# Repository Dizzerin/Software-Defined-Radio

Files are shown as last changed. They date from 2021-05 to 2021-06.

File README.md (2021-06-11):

# Software-Defined-Radio
This project is a quadrature sampling down converter software defined radio reciver for Engineering Electronics II at Walla Walla University.
My partners for this project were [Darius Felder](https://github.com/darius3241) and [Eric Walsh](https://github.com/Eric-Walsh).
For a quick look at the final results of our project jump to [results](#results).
For a quick setup guide jump to [Quisk setup](#quisk-setup).

## Design Objectives
Our professor, [Dr. Rob Frohne](https://github.com/frohro), gave us the following design objectives:
  1. Minimum discernible signal less than 1μV
  2. Good image rejection
  3. Low noise figure
  4. Inexpensive to build

  1. **Simple Design**: We wanted our design to be easy to understand and construct
  2. **Ease of Construction**: We wanted to build a simple radio that works
  3. **Low Cost**: Our budget for this project was $30
  
## Overview
The Software Defined Radio (SDR) receiver connects to an antenna and covers the filtering, mixing, and amplification of the desired signal. It then connects a sound card within a computer and software handles the demodulation of the signal into playable audio. The mixing is handled using an Arduino Nano running code provided to us by our Professor, [Dr. Rob Frohne](https://github.com/frohro), which interfaces with [Quisk](https://james.ahlstrom.name/quisk/), an SDR that controls the receiver through the Arduino. Using Quisk, the radio can be tuned to a certain frequency by adjusting the speed of the local oscillator used in the mixing process. Our budget on this project to keep with the low-cost aspect was about $30 including fabrication of the PCB and the required components. 

Note: Overview section by [Konrad McClure](https://github.com/KonradMcClure)

## Theory
The basics of the SDR Receiver are shown below in the block diagram, with the blue components being defined by software. An antenna picks up the radio signal and passes it through a bandpass filter. This filter will attenuate any signals outside our desired range of 6–16 MHz. This is then passed through a Tayloe Mixer, also known as the Tayloe Quadrature Product Detector. The Tayloe Mixer is a simple and efficient mixer that uses a 1:4 demultiplexer and operational amplifiers to generate the I and Q quadrature signals for demodulation. After the signal has been split into four bandbase signals, they are amplified and combined into the I and Q quadrature signals. Those signals go through a final Low-Pass filter that will attenuate signals above 100KHz in frequency, effectively smoothing the output signal. This signal is then sent via 3.5mm audio cable to the soundcard which demodulates the signal. Quisk can then read the input from the sound card and play it. Quisk also interfaces to the Arduino Nano to set the speed of the local oscillator for tuning into the desired frequency.

Note: This Theory Section is a slightly modified version of work originally written by [Konrad McClure](https://github.com/KonradMcClure)

## Design 
Here is a basic block diagram of our design:



## Schematic 


### List of components


### Voltage smoother 
This was added to smooth out 5V power supply from USB. This will help elimate supply noise.



### Voltage converter
This device converts the 5V logic of the arduino nano to the 3.3V logic of the Si5351a for both directions.



### Local Oscillator (Si5351a)
The local oscillator we used, SI5351-AB-GT clock generator was selected largely due to the fact that Dr. Frohne has used this chip with success.



### Mixer (tayloe)
The Tayloe Mixer is a mixer design as seen in [this paper](http://www.norcalqrp.org/files/Tayloe_mixer_x3a.pdf) by Dan Tayloe. We chose it due to its relatively simple and elegant design. It utilizes a [two-channel SN74CBT multiplexer](http://www.ti.com/lit/ds/symlink/sn74cbt3253.pdf?ts=1591655665924) and a pair of [INA821ID single gain resistor instrumentation amplifiers](http://www.ti.com/lit/ds/symlink/ina821.pdf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). To be more specific, Tayloe describes this as a "switching integrator," rather than a mixer, since a mixer normally produces both a sum and difference frequency of the RF and LO signals.



### Amplifiers
A Multiple feedback low pass filter and amplifier was used.



### Arduino Nano


## Simulation
Complete LTSpice model:



### Results of simulation


## Quisk setup
According to the [Quisk pip project description](https://pypi.org/project/quisk/), the [Quisk software](https://james.ahlstrom.name/quisk/) is "Software Defined Radio (SDR) transceiver software. You supply radio hardware that converts signals at the antenna to complex (I/Q) data at an intermediate frequency (IF). Data can come from a sound card, Ethernet or USB. Quisk then filters and demodulates the data and sends the audio to your speakers or headphones."  We used Quisk in our project for just this purpose.

To get Quisk up and running with our radio, simply:
1. Flash the [openradio_quisk.ino](openradio_quisk.ino) file to the arduino nano microcontroller.
2. Start Quisk and configure a new radio.  Point Quisk to the [quisk_conf_openradio.py](quisk_conf_openradio.py) file.  Alternatively you can simply copy the file to your home directory (~/.quisk_conf.py).

	Note: You may need to configure the following settings in this python file:
	* Sound card settings
	* Serial port settings
	
3. Restart Quisk tune to your desired frequency and listen away!

## Board build up plan 
See [board build up plan](https://github.com/darius3241/Software-Defined-Radio/wiki/Board-build-up-plan).

## Revisions and debugging 
See [revisions and debugging](https://github.com/darius3241/Software-Defined-Radio/wiki/Debugging-and-Revisions).

## Complete Design 
Photo of our complete board:



## Results
In the end, we had about 1μV of sensitivity and between 10 and 30 dB of image rejection. (Darius’
radio had about 10dB of rejection while mine had about 30dB of image rejection). Though our radios
are working, they have less sensitivity than desired and when we examine the waterfall spectral display
on Quisk there are some distinct lines. We believe these are from signals on the USB input, so it may be
worthwhile to investigate isolating this further in future revisions.

Credit to: Dr. Frohne for his extensive help with the debugging process.

## Future Revision Recomendations
Other recommendations for future revisions include using continuous rows of pin headers for test
points instead of single pin headers to ease soldering, include better ground test points (perhaps two
pads to solder a wire between which ground clips can be clipped onto), moving plastic components
further from surface mount chips which may need to be de-soldered, and including jumpers to allow the
op amps to be powered from an alternate power source separate from the 5V circuit so additional
power can be provided if desired without damaging other components.

## External tools used:
[Multiple Feedback Low-Pass Filter Design Tool](http://sim.okawa-denshi.jp/en/OPtazyuLowkeisan.htm)

[Third Order Butterworth Bandpass Filter Design Tool](https://rf-tools.com/lc-filter/)

## Credits
[Darius Felder](https://github.com/darius3241) - project partner primarily responsible for testing, simulations, and documentation

[Eric Walsh](https://github.com/Eric-Walsh) - project partner primarily responsible for testing and LTSpice simulations

[Dr. Frohne](https://github.com/frohro) - class professor

[Konrad McClure](https://github.com/KonradMcClure) - previous project pioneer

[Caleb Froelich](https://github.com/froeca) - previous project pioneer

[Jordyn Watkins](https://github.com/greenjacketgirl) - previous project pioneer

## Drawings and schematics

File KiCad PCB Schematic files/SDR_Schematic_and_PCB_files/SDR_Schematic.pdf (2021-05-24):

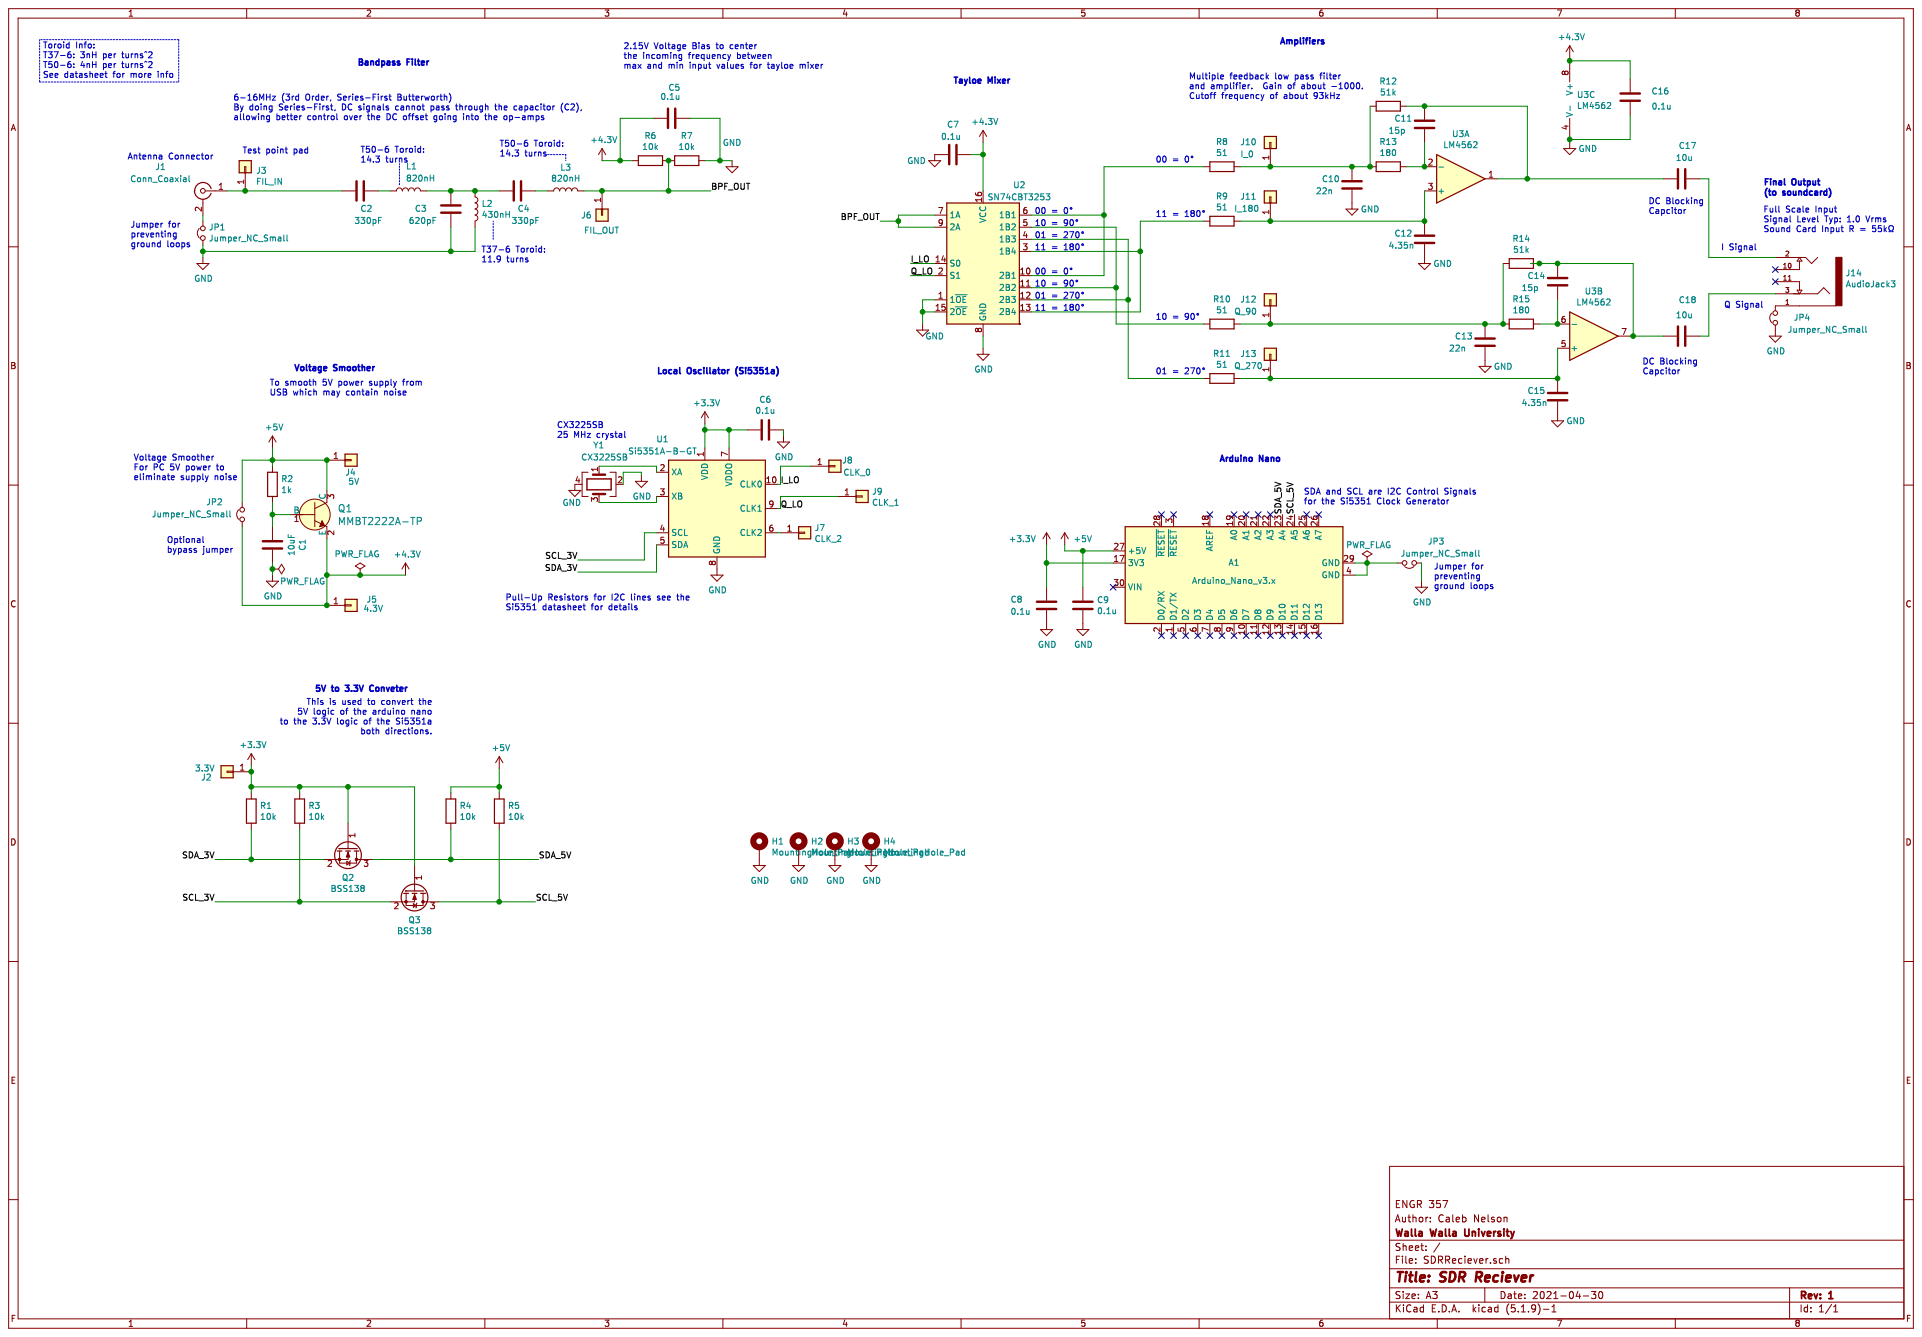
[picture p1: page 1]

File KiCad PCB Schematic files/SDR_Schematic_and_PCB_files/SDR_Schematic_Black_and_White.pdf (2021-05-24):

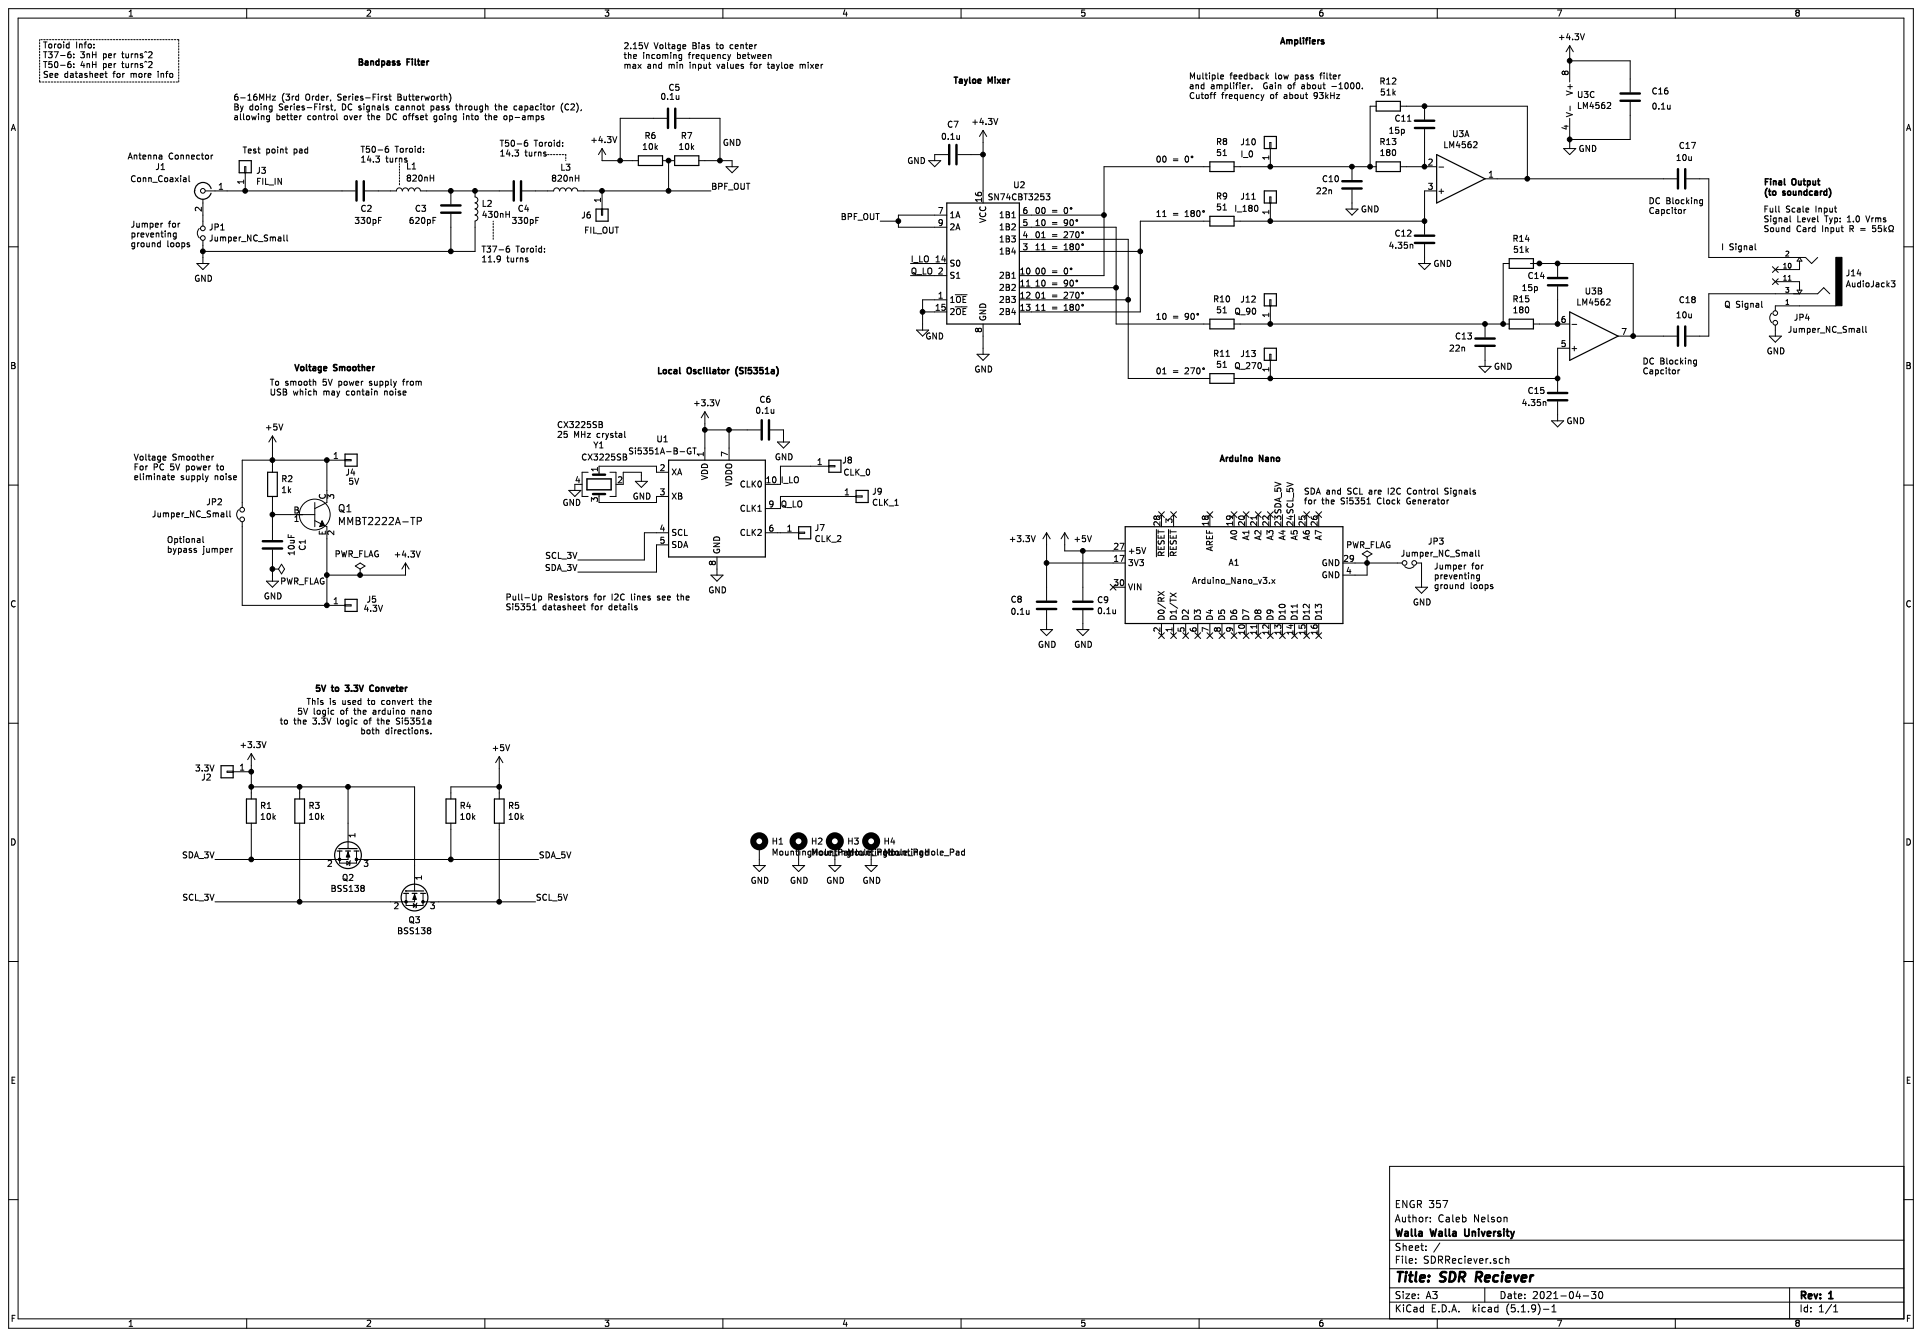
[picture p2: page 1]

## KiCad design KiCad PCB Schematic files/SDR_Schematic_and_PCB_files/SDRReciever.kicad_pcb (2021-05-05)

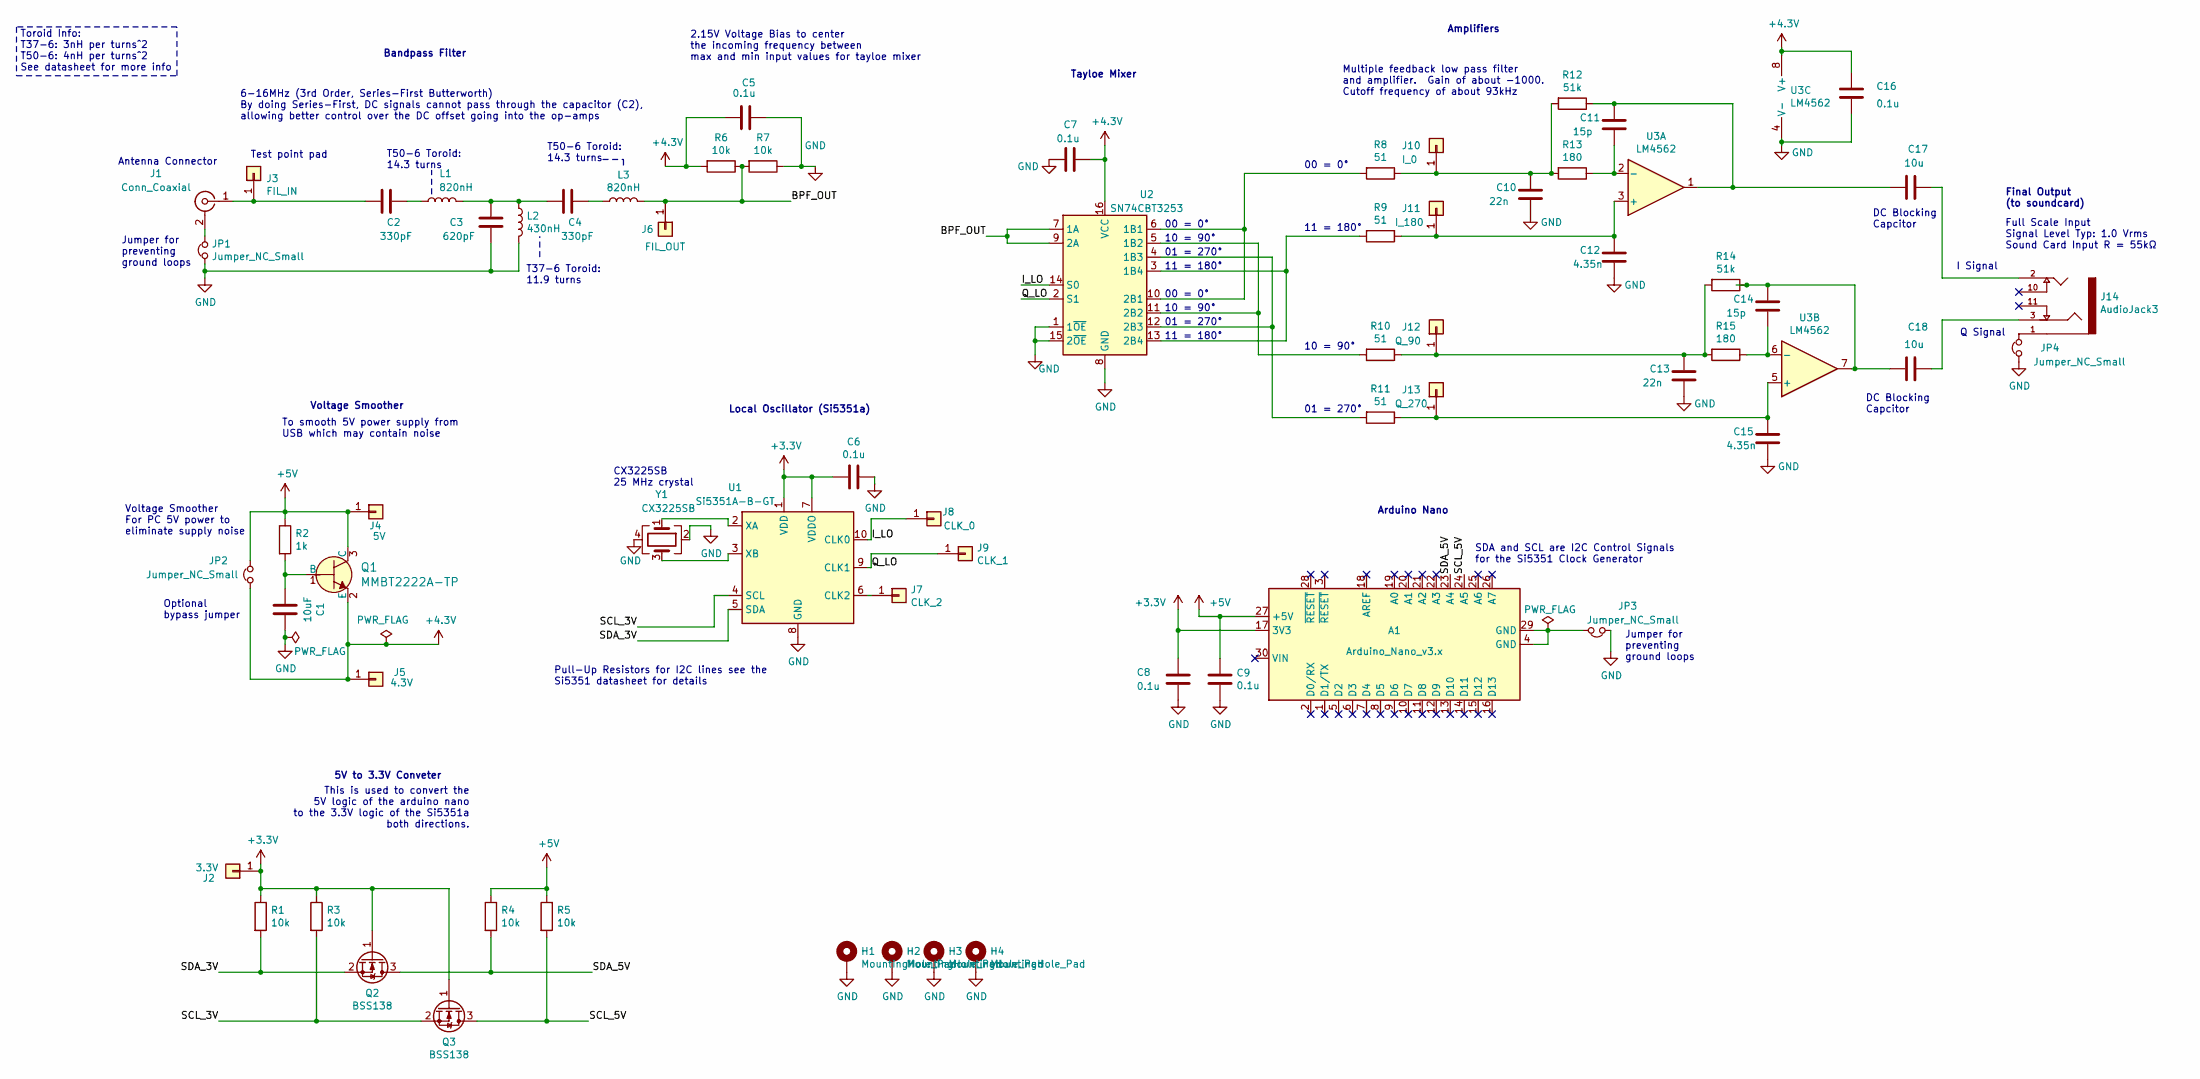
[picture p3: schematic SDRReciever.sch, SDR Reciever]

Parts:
A1: Arduino_Nano_v3.x; Arduino_Nano
C1: 10uF; C_0805_2012Metric
C2, C4: 330pF; C_0805_2012Metric
C3: 620pF; C_0805_2012Metric
C5, C6, C7, C8, C9, C16: 0.1u; C_0805_2012Metric
C10, C13: 22n; C_0805_2012Metric
C11, C14: 15p; C_0805_2012Metric
C12, C15: 4.35n; C_0805_2012Metric
C17, C18: 10u; C_0805_2012Metric
H1, H2, H3, H4: MountingHole_Pad; MountingHole_2.2mm_M2_Pad
J1: Conn_Coaxial; BNC_Amphenol_B6252HB-NPP3G-50_Horizontal
J2: 3.3V; PinHeader_1x01_P2.54mm_Vertical
J3: FIL_IN; PinHeader_1x01_P2.54mm_Vertical
J4: 5V; PinHeader_1x01_P2.54mm_Vertical
J5: 4.3V; PinHeader_1x01_P2.54mm_Vertical
J6: FIL_OUT; PinHeader_1x01_P2.54mm_Vertical
J7: CLK_2; PinHeader_1x01_P2.54mm_Vertical
J8: CLK_0; PinHeader_1x01_P2.54mm_Vertical
J9: CLK_1; PinHeader_1x01_P2.54mm_Vertical
J10: I_0; PinHeader_1x01_P2.54mm_Vertical
J11: I_180; PinHeader_1x01_P2.54mm_Vertical
J12: Q_90; PinHeader_1x01_P2.54mm_Vertical
J13: Q_270; PinHeader_1x01_P2.54mm_Vertical
J14: AudioJack3; 35RAPC4BHN2
JP1, JP2, JP3, JP4: Jumper_NC_Small; PinHeader_1x02_P2.54mm_Vertical
L1, L3: 820nH; L_Toroid_Vertical_L13.0mm_W6.5mm_P5.60mm
L2: 430nH; L_Toroid_Vertical_L10.0mm_W5.0mm_P5.08mm
Q1: MMBT2222A-TP; SOT-23-3; MPN MMBT2222A-TP; Digi-Key_PN MMBT2222ATPMSCT-ND
Q2, Q3: BSS138; SOT-23
R1, R3, R4, R5, R6, R7: 10k; R_0805_2012Metric
R2: 1k; R_0805_2012Metric
R8, R9, R10, R11: 51; R_0805_2012Metric
R12, R14: 51k; R_0805_2012Metric
R13, R15: 180; R_0805_2012Metric
U1: Si5351A-B-GT; MSOP-10_3x3mm_P0.5mm
U2: SN74CBT3253; SOIC-16_3.9x9.9mm_P1.27mm
U3: LM4562; SOIC-8_3.9x4.9mm_P1.27mm
Y1: CX3225SB; Crystal_SMD_Abracon_ABM8G-4Pin_3.2x2.5mm

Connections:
+3V3: A1.17 (3V3), C6.2, C8.1, J2.1, Q2.1 (G), Q3.1 (G), R1.1, R3.1, U1.1 (VDD), U1.7 (VDDO)
+4.3V: C5.1, C7.1, C16.1, J5.1, JP2.1, Q1.2 (E), R6.2, U2.16 (VCC), U3.8 (V+)
+5V: A1.27 (+5V), C9.1, J4.1, JP2.2, Q1.3 (C), R2.1, R4.1, R5.1
/BPF_OUT: J6.1, L3.2, R6.1, R7.2, U2.7 (1A), U2.9 (2A)
/I_LO: J8.1, U1.10 (CLK0), U2.14 (S0)
/Q_LO: J9.1, U1.9 (CLK1), U2.2 (S1)
/SCL_3V: Q3.2 (S), R3.2, U1.4 (SCL)
/SCL_5V: A1.24 (A5), Q3.3 (D), R5.2
/SDA_3V: Q2.2 (S), R1.2, U1.5 (SDA)
/SDA_5V: A1.23 (A4), Q2.3 (D), R4.2
GND: C1.1, C3.1, C5.2, C6.1, C7.2, C8.2, C9.2, C10.2, C12.2, C13.2, C15.2, C16.2, H1.1, H2.1, H3.1, H4.1, JP1.1, JP3.1, JP4.1, L2.2, R7.1, U1.8 (GND), U2.1 (1~OE), U2.8 (GND), U2.15 (2~OE), U3.4 (V-), Y1.2, Y1.4
unnamed: A1.4 (GND), A1.29 (GND), JP3.2
unnamed: C1.2, Q1.1 (B), R2.2
unnamed: C2.1, J1.1 (In), J3.1
unnamed: C2.2, L1.1
unnamed: C3.2, C4.1, L1.2, L2.1
unnamed: C4.2, L3.1
unnamed 17: C10.1, J10.1, R8.1, R12.2, R13.2; also elsewhere on the board
unnamed: C11.1, C17.2, R12.1, U3.1
unnamed: C11.2, R13.1, U3.2 (-)
unnamed 20: C12.1, J11.1, R9.1, U3.3 (+); also elsewhere on the board
unnamed 21: C13.1, J12.1, R10.1, R14.2, R15.2; also elsewhere on the board
unnamed: C14.1, C18.2, R14.1, U3.7
unnamed: C14.2, R15.1, U3.6 (-)
unnamed 24: C15.1, J13.1, R11.1, U3.5 (+); also elsewhere on the board
unnamed: C17.1, J14.2
unnamed: C18.1, J14.3
unnamed: J1.2 (Ext), JP1.2
unnamed: J7.1, U1.6 (CLK2)
unnamed: J14.1, JP4.2
unnamed: R8.2, U2.6 (1B1), U2.10 (2B1)
unnamed: R9.2, U2.3 (1B4), U2.13 (2B4)
unnamed: R10.2, U2.5 (1B2), U2.11 (2B2)
unnamed: R11.2, U2.4 (1B3), U2.12 (2B3)
unnamed: U1.2 (XA), Y1.1
unnamed: U1.3 (XB), Y1.3

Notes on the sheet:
2.15V Voltage Bias to center the incoming frequency between max and min input values for tayloe mixer
Full Scale Input Signal Level Typ: 1.0 Vrms Sound Card Input R = 55kΩ
Multiple feedback low pass filter and amplifier. Gain of about -1000. Cutoff frequency of about 93kHz
Voltage Smoother For PC 5V power to eliminate supply noise
T50-6 Toroid: 14.3 turns
T37-6 Toroid: 11.9 turns
Pull-Up Resistors for I2C lines see the Si5351 datasheet for details
SDA and SCL are I2C Control Signals for the Si5351 Clock Generator
Jumper for preventing ground loops
CX3225SB 25 MHz crystal
00 = 0°
11 = 180°
10 = 90°
01 = 270°
6-16MHz (3rd Order, Series-First Butterworth) By doing Series-First, DC signals cannot pass through the capacitor (C2), allowing better control over the DC offset going into the op-amps
Toroid Info: T37-6: 3nH per turns^2 T50-6: 4nH per turns^2 See datasheet for more info
Antenna Connector
Test point pad
Bandpass Filter
Local Oscillator (Si5351a)
Arduino Nano
Tayloe Mixer
Final Output (to soundcard)
5V to 3.3V Conveter
This is used to convert the 5V logic of the arduino nano to the 3.3V logic of the Si5351a both directions.
I Signal
Amplifiers
Q Signal
Voltage Smoother
To smooth 5V power supply from USB which may contain noise
Optional bypass jumper
DC Blocking Capcitor

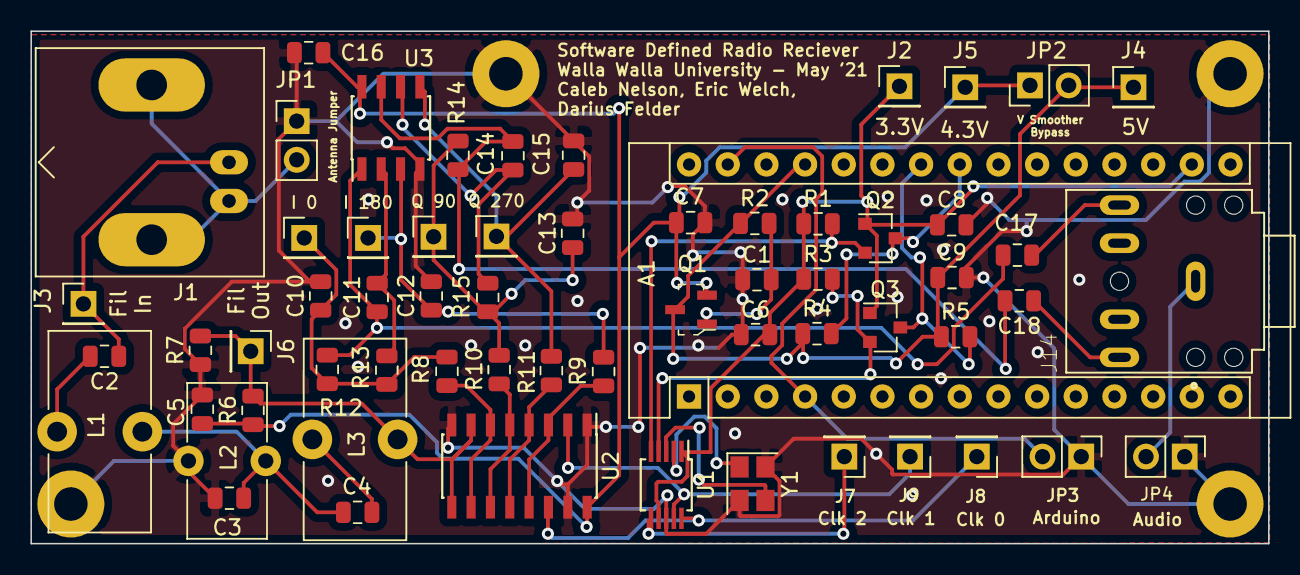
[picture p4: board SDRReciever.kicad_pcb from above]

Board: 2 copper layers, 81.3 x 33.7 mm, 66 parts (0 on the bottom side), 36 nets.

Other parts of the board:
I 0: I_0; PinHeader_1x01_P2.54mm_Vertical
I 180: I_180; PinHeader_1x01_P2.54mm_Vertical
Q 90: Q_90; PinHeader_1x01_P2.54mm_Vertical
Q 270: Q_270; PinHeader_1x01_P2.54mm_Vertical

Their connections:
unnamed 17: I 0.1; also elsewhere on the board
unnamed 20: I 180.1; also elsewhere on the board
unnamed 21: Q 90.1; also elsewhere on the board
unnamed 24: Q 270.1; also elsewhere on the board

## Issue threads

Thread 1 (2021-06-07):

DC Offset Voltage Is Not Right

frohro, 2021-06-07:
Hi Caleb, Darius, and Eric,
The DC bias created by R6 and R7 is not centered quite right.  The Q channel saturates because of this.  I found that a pot in parallel with that can fix the problem, but on the PCB you may just be able to change the resistor values.  Perhaps putting in a small pot in between R6 and R7 might be a good way too in a future PCB.
Thanks,
Rob

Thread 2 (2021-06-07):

Si5351a too close to the Arduino socket

frohro, 2021-06-07:
Removing the Si5351 (or even the mixer) makes it very likely to melt the socket of the Arduino, which is a real pain to fix.  Maybe the next PCB revision could have that revised.

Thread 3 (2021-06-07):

Using a higher Op-Amp Supply Voltage

frohro, 2021-06-07:
Hi All,
It would be nice to have the option of using a higher voltage to supply the op-amp.  It would keep your receiver from saturating with larger signals that it saturates with now.  It would also help with the op-amp saturation problem.  The problem  of using the +5V to put in an external voltage is that if you use more than that you will damage the mixer chip.  Some ideas are using jumpers to select the voltage you want.  You could possibly power the mixer chip from the Arduino which has an onboard regulator (not used in your design), or you could use an external regulator setup.
Thanks,
Rob

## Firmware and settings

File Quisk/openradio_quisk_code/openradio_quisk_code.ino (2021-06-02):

/*
  OpenRadio Quisk Interface 
  Main
  This is used to provide a serial interface which Quisk SDR can talk to.
  
  Copyright (C) 2014 Mark Jessop <vk5qi@rfhead.net>

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
    For a full copy of the GNU General Public License, 
    see <http://www.gnu.org/licenses/>.

   Command Reference:
    ------------------
    All commands consist of an identifier, followed by one or more parameters delinieated by commas, then a newline.
    i.e.:
    COMMAND,<param1>,<param2><LF>
    
    A command will return OK<LF> if successful, and ERROR<LF> if not. Some commands (particuarly transmit commands)
    may take a significant amount of time to return.
    
    Sending a command which takes parameters, without sending the parameters, will return the set parameters.
    
    Frequency Settings:
    
    FREQ,<freq> 		- Set the center freq of the receiver, in Hz.
    FREQPSK,<freq>		- Set the transmit frequency, in Hz.

    Modulation:
    All transmissions will time out after 10 minutes. (if we implement it)
    
    CARRIER,<ON/OFF>	- Transmit a carrier.
    PSK,<rate>,message	- Send message using Phase Shift Keying, with the specified symbol rate.
*/

#include <stdlib.h>
#include <string.h>
#include <errno.h>
#include <avr/pgmspace.h>
#warning __PGMSPACE_H_
#include <EEPROM.h>
#include <Wire.h>
#include "si5351.h"
#include "TimerOne.h"
#include "settings.h"
#include "pins.h"
#include "ring_buffer.h"

#define VERSION "0.3"

// Default output frequency
#define RX_FREQ 27000000
#define TX_FREQ 27000000
#define FREQ_LIMIT_LOWER 100000
#define FREQ_LIMIT_UPPER 30000000

#define SERIAL_BAUD     57600

Si5351 si5351;

int tx_relay_state = 0;
int tx_state = 0;

static struct settings settings;

// Ring buffer for use with the interrupt-driven transmit buffer.
struct ring_buffer data_tx_buffer = { { 0 }, 0, 0};

/* Returns true if settings are valid */
static bool read_settings(void)
{
    uint8_t *p = (uint8_t *)&settings;
    int i = 0;

    while(i < sizeof(struct settings))
        *p++ = EEPROM.read(i++);

    return settings.magic == SETTINGS_MAGIC;
}

static void write_settings(void)
{
    uint8_t *p = (uint8_t *)&settings;
    int i = 0;

    // Invalidate checksum to guard against partial writes
    EEPROM.write(0, 0);

    while(i < sizeof(struct settings))
        EEPROM.write(i++, *p++);
}

// Input buffer for reading user input.
#define INPUTBUFLEN	64
//char inputBuffer[INPUTBUFLEN];
int inputBufferPtr = 0;
char tempBuffer[20]; // Buffer for string to int conversion.
String inputBuffer = "";

void setup(){
    // Initialise things.
    pinMode(TX_RX_SWITCH, OUTPUT);
    digitalWrite(TX_RX_SWITCH, LOW);
    pinMode(MODULATION, OUTPUT);
    digitalWrite(MODULATION, LOW);
    pinMode(LED, OUTPUT);
    digitalWrite(LED, LOW);

    Serial.begin(SERIAL_BAUD);
    Serial.setTimeout(1000 * 10);

    uint8_t rev_id = si5351_init();

    // Click the relay as an 'audible' startup indicator.
    digitalWrite(TX_RX_SWITCH, HIGH);
    delay(300);
    digitalWrite(TX_RX_SWITCH, LOW);

    if (!read_settings()) {
        //Serial.println(F("Resetting settings to defaults"));
        settings.magic = SETTINGS_MAGIC;
        settings.rx_freq = RX_FREQ;
        settings.tx_freq = TX_FREQ;
        settings.cal_factor = 1.0f;
    }

    set_rx_freq(settings.rx_freq);
    set_tx_freq(settings.tx_freq);


}

void loop(){
	if(Serial.available()){
		// Read in a byte.
		char inChar = (char)Serial.read();
		
		// Work out what the character is. If letters or numbers, add to
		// the buffer, if not, don't add.
		
		// If character is a newline, we have reached the end of the command.
		if( (inChar == '\n') || (inputBufferPtr>INPUTBUFLEN)){
			// Parse string
			if( parseCommand(inputBuffer)==0 ){
				Serial.println("OK");
			}else{
				Serial.println("ERROR");
			}
			inputBuffer = "";
			inputBufferPtr = 0;
		}else if( isalnum(inChar) || ispunct(inChar) || isblank(inChar) || inChar==4 ){
			// Add to the input buffer if printable and not a line ending.
			inputBuffer += inChar;
			inputBufferPtr++;
		}
	}
}

// CSV parser function. Splits input into arguments.
// I am so sorry...
int parseCommand(String input){
	int params = 0;
	
	if(input.length()<3){
		// No command is shorter than 3 characters. Error.
		return 1;
	}
	// At this point we have found some sort of command (maybe)
	

	// Search through for commas, populate an array of pointers, make pointer = -1 if nothing found.
	// NOTE: This is a horrible bit of code. If theres is a better way to do CSV parsing in Arduino, let me know!
	int separators[] = {-1,-1,-1,-1,-1,-1};

	separators[0] = input.indexOf(",");
	
	if(separators[0] != -1){ // If we find one comma, maybe there are more...
		int i = 1;
		while((separators[i-1] != -1) && i<6){
			params++;
			separators[i] = input.indexOf(",", separators[i-1]+1);
			i++;
		}
	
	}

	if(params==0){ // Either a request command or a command with no parameter
		if(input.startsWith("FREQPSK")){
			Serial.print("FREQPSK,"); Serial.println(settings.tx_freq);
			return 0;
		}else if(input.startsWith("FREQ")){
			Serial.print("FREQ,"); Serial.println(settings.rx_freq);
			return 0;
		}else if(input.startsWith("CAL")){
			Serial.print("CAL,"); Serial.println(settings.cal_factor,10);
			return 0;
		}else if(input.startsWith("VER")){
			Serial.print("VER,"); Serial.println("OpenRadio V1.1");
			return 0;
		}else{
			// No other commands are valid without parameters. Error
			return 1;
		}
	}else if(params==1){ // Commands with one argument.
		String param1 = input.substring(separators[0]+1); // Extract the argument for passing to the function.
		if(input.startsWith("FREQPSK")){
			return parsePSKFreq(param1);
		}else if(input.startsWith("FREQ")){
			return parseFreq(param1);
		}else if(input.startsWith("PSKFREQ")){
			return parsePSKFreq(param1);
		}else if(input.startsWith("CARRIER")){
			return parseCarrier(param1);
		}else if(input.startsWith("CHAN")){
			return set_channel(param1);
		}else{
			// No other commands are valid with only one parameter. Error
			return 1;
		}
	}else if(params==2){ // Commands with 2 parameters (PSK);
		String param1 = input.substring(separators[0]+1, separators[1]);
		String param2 = input.substring(separators[1]+1);
		
		if(input.startsWith("PSK")){
			return psk_transmit(param1,param2);
		}else{
			// No other commands are valid with only one parameter. Error
			return 1;
		}
	}

	return 1; // Cannot parse command, error.
}

int freqValid(uint32_t freq){
	return (freq>FREQ_LIMIT_LOWER) && (freq<FREQ_LIMIT_UPPER);
}

// Parse frequency, program radio.
int parseFreq(String input){
	unsigned long result = 0;
	unsigned long combinedresult = 0;
	char* endptr;
	
	input.toCharArray(tempBuffer,10);
	
	result = strtoul(tempBuffer,&endptr,10);
	// If strtoul fails to convert, *endptr contains the character which conversion failed on.
	// Otherwise, *endptr contains '\0'.
	if(*endptr != 0) return -1;
	
	if(freqValid(result)){
		set_rx_freq(result);
		Serial.print("FREQ,");Serial.println(result);
		return 0;
	}else{
		//Serial.println("Invalid input.");
		return -1;
	}	
}

// Carrier on/off
// This should transmit a carrier at an offset from the rx freq.
// We probably dont need this right now.
int parseCarrier(String carrier_str){
// TODO

}

// Transit a string of PSK (message) at (rate) baud.
// We need to figure out how to decide what the 'offset' from the RF freq is.
// Maybe add another command to set this?
int parsePSK(String rate, String message){
// TODO

}

// Set the frequency of the transmitted PSK signal.
// This is entirely independent of the receive chain, and we should
// be controlling if we want to lock this to within the RX passband 
// from within the client software.
int parsePSKFreq(String input){
	unsigned long result = 0;
	unsigned long combinedresult = 0;
	char* endptr;
	
	input.toCharArray(tempBuffer,10);
	
	result = strtoul(tempBuffer,&endptr,10);
	// If strtoul fails to convert, *endptr contains the character which conversion failed on.
	// Otherwise, *endptr contains '\0'.
	if(*endptr != 0) return -1;
	
	if(freqValid(result)){
		set_tx_freq(result);
		Serial.print("FREQPSK,");Serial.println(result);
		return 0;
	}else{
		//Serial.println("Invalid input.");
		return -1;
	}	

}


//
// Si5351 Helper Functions
//

uint8_t si5351_init(){
    si5351.init(SI5351_CRYSTAL_LOAD_8PF,0,0);
    si5351.set_pll(SI5351_PLL_FIXED, SI5351_PLLA);
    // Set output frequencies
    set_rx_freq(RX_FREQ);
    set_tx_freq(TX_FREQ);

    // Enable RX, and disable TX by default.
    si5351.output_enable(RX_CLOCK,1);
    si5351.output_enable(TX_CLOCK,0);
    si5351.output_enable(SPARE_CLOCK,0);

    // Read the status register and return the chip revision ID.
    si5351.update_status();
    return si5351.dev_status.REVID;

}

static void set_rx_freq(uint32_t freq)
{
    // Save actual value
    settings.rx_freq = freq;

    // Quadrature mixer requires LO signal.
    si5351.set_freq(freq * settings.cal_factor, RX_CLOCK);

	if( freq <= 4.0e6) {
		digitalWrite(S0, HIGH);
		digitalWrite(S1, HIGH);
	}
	else if (freq <= 8.0e6) {
		digitalWrite(S0, LOW);
		digitalWrite(S1, HIGH);
	}
	else if (freq <= 16.0e6) {
		digitalWrite(S0, HIGH);
		digitalWrite(S1, LOW);
	}
	else {
		digitalWrite(S0, LOW);
		digitalWrite(S1, LOW);
	}				
}

static void set_tx_freq(uint32_t freq)
{
    // Save actual value
    settings.tx_freq = freq;

    // Let driver choose PLL settings. May glitch when changing frequencies.
    si5351.set_freq(freq * settings.cal_factor, TX_CLOCK);
}

void tx_enable(){
    si5351.output_enable(TX_CLOCK,1);
    tx_state = 1;
}

void tx_disable(){
    si5351.output_enable(TX_CLOCK,0);
    tx_state = 0;
}

void tx(){
    digitalWrite(TX_RX_SWITCH, HIGH);
    digitalWrite(LED, HIGH);
    tx_relay_state = 1;
}

void rx(){
    digitalWrite(TX_RX_SWITCH, LOW);
    digitalWrite(LED, LOW);
    tx_relay_state = 0;
}

#define MIN_CHANNEL 1
#define MAX_CHANNEL 30


#ifdef USE_FLASH
// From https://docs.google.com/spreadsheets/d/1KP5XsAHPCD2FsUW5RoqCfCJYRt2o03q6RN2TroPgEKk/edit#gid=0
const prog_uint16_t channel_list[] =
#else
const uint16_t channel_list[] =
#endif
        {8986, 8990, 8993, 8996, 9000, 9003, 9006, 9010, 9013, 9016, 9020, 9023, 9026,
        9030, 9033, 9036, 9040, 9043, 9046, 9050, 9053, 9056, 9060, 9063, 9066, 9070,
        9073, 9076, 9080, 9083};

int set_channel(String input)
{
	unsigned long chan = 0;
	char* endptr;
	
	input.toCharArray(tempBuffer,10);
	
	chan = strtoul(tempBuffer,&endptr,10);
	// If strtoul fails to convert, *endptr contains the character which conversion failed on.
	// Otherwise, *endptr contains '\0'.
	if(*endptr != 0) return -1;



    if (chan < MIN_CHANNEL || chan > MAX_CHANNEL) {
        return 1;
    }

#ifdef USE_FLASH
    uint32_t rx = (uint32_t)pgm_read_word_near(channel_list + chan-1) * 1000;
#else
    uint32_t rx = (uint32_t)channel_list[chan-1] * 1000;
#endif
    uint32_t tx = rx * 3 + 1500;

    set_rx_freq(rx);
    set_tx_freq(tx);

    // Save settings
    write_settings();

    Serial.print("CHAN,"); Serial.println(chan);
    return 0;
}

int psk_transmit(String param1, String param2){
	unsigned long baud_rate = 0;
	char* endptr;
	
	param1.toCharArray(tempBuffer,10);
	
	baud_rate = strtoul(tempBuffer,&endptr,10);
	// If strtoul fails to convert, *endptr contains the character which conversion failed on.
	// Otherwise, *endptr contains '\0'.
	if(*endptr != 0) return -1;

    tx();
    tx_enable();
    if (!bpsk_start(baud_rate)){
    	tx_disable();
    	rx();
        return 1;
    }
    delay(300); //  Short delay for RX sync to occur.
    // Push string into ring buffer for transmission.
    for(int i = 0; i<param2.length(); i++){
    	store_char(param2.charAt(i),&data_tx_buffer);
    }
    // Send an EOT control character, then a newline, to signify the end of the message.
    store_char((char)4, &data_tx_buffer);
    store_char('\n', &data_tx_buffer);
    while(data_waiting(&data_tx_buffer)>0){}
    delay(300);
    bpsk_stop();
    tx_disable();
    rx();

    return 0;
}

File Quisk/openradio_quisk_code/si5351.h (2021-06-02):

/*
 * si5351.h - Si5351 library for Arduino
 *
 * Copyright (C) 2015 - 2019 Jason Milldrum <milldrum@gmail.com>
 *                           Dana H. Myers <k6jq@comcast.net>
 *
 * Many defines derived from clk-si5351.h in the Linux kernel.
 * Sebastian Hesselbarth <sebastian.hesselbarth@gmail.com>
 * Rabeeh Khoury <rabeeh@solid-run.com>
 *
 * do_div() macro derived from /include/asm-generic/div64.h in
 * the Linux kernel.
 * Copyright (C) 2003 Bernardo Innocenti <bernie@develer.com>
 *
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
 * You should have received a copy of the GNU General Public License
 * along with this program.  If not, see <http://www.gnu.org/licenses/>.
 */

#ifndef SI5351_H_
#define SI5351_H_

#include "Arduino.h"
#include "Wire.h"
#include <stdint.h>

/* Define definitions */

// Default: ---> #define SI5351_BUS_BASE_ADDR            0x60
#define SI5351_BUS_BASE_ADDR            0x62
#define SI5351_XTAL_FREQ                25000000
#define SI5351_PLL_FIXED                80000000000ULL
#define SI5351_FREQ_MULT                100ULL
#define SI5351_DEFAULT_CLK              1000000000ULL

#define SI5351_PLL_VCO_MIN              600000000
#define SI5351_PLL_VCO_MAX              900000000
#define SI5351_MULTISYNTH_MIN_FREQ      500000
#define SI5351_MULTISYNTH_DIVBY4_FREQ   150000000
#define SI5351_MULTISYNTH_MAX_FREQ      225000000
#define SI5351_MULTISYNTH_SHARE_MAX     100000000
#define SI5351_MULTISYNTH_SHARE_MIN     1024000
#define SI5351_MULTISYNTH67_MAX_FREQ    SI5351_MULTISYNTH_DIVBY4_FREQ
#define SI5351_CLKOUT_MIN_FREQ          4000
#define SI5351_CLKOUT_MAX_FREQ          SI5351_MULTISYNTH_MAX_FREQ
#define SI5351_CLKOUT67_MS_MIN          SI5351_PLL_VCO_MIN / SI5351_MULTISYNTH67_A_MAX
#define SI5351_CLKOUT67_MIN_FREQ        SI5351_CLKOUT67_MS_MIN / 128
#define SI5351_CLKOUT67_MAX_FREQ        SI5351_MULTISYNTH67_MAX_FREQ

#define SI5351_PLL_A_MIN                15
#define SI5351_PLL_A_MAX                90
#define SI5351_PLL_B_MAX                (SI5351_PLL_C_MAX-1)
#define SI5351_PLL_C_MAX                1048575
#define SI5351_MULTISYNTH_A_MIN         6
#define SI5351_MULTISYNTH_A_MAX         1800
#define SI5351_MULTISYNTH67_A_MAX       254
#define SI5351_MULTISYNTH_B_MAX         (SI5351_MULTISYNTH_C_MAX-1)
#define SI5351_MULTISYNTH_C_MAX         1048575
#define SI5351_MULTISYNTH_P1_MAX        ((1<<18)-1)
#define SI5351_MULTISYNTH_P2_MAX        ((1<<20)-1)
#define SI5351_MULTISYNTH_P3_MAX        ((1<<20)-1)
#define SI5351_VCXO_PULL_MIN            30
#define SI5351_VCXO_PULL_MAX            240
#define SI5351_VCXO_MARGIN              103

#define SI5351_DEVICE_STATUS            0
#define SI5351_INTERRUPT_STATUS         1
#define SI5351_INTERRUPT_MASK           2
#define SI5351_STATUS_SYS_INIT          (1<<7)
#define SI5351_STATUS_LOL_B             (1<<6)
#define SI5351_STATUS_LOL_A             (1<<5)
#define SI5351_STATUS_LOS               (1<<4)
#define SI5351_OUTPUT_ENABLE_CTRL       3
#define SI5351_OEB_PIN_ENABLE_CTRL      9
#define SI5351_PLL_INPUT_SOURCE         15
#define SI5351_CLKIN_DIV_MASK           (3<<6)
#define SI5351_CLKIN_DIV_1              (0<<6)
#define SI5351_CLKIN_DIV_2              (1<<6)
#define SI5351_CLKIN_DIV_4              (2<<6)
#define SI5351_CLKIN_DIV_8              (3<<6)
#define SI5351_PLLB_SOURCE              (1<<3)
#define SI5351_PLLA_SOURCE              (1<<2)

#define SI5351_CLK0_CTRL                16
#define SI5351_CLK1_CTRL                17
#define SI5351_CLK2_CTRL                18
#define SI5351_CLK3_CTRL                19
#define SI5351_CLK4_CTRL                20
#define SI5351_CLK5_CTRL                21
#define SI5351_CLK6_CTRL                22
#define SI5351_CLK7_CTRL                23
#define SI5351_CLK_POWERDOWN            (1<<7)
#define SI5351_CLK_INTEGER_MODE         (1<<6)
#define SI5351_CLK_PLL_SELECT           (1<<5)
#define SI5351_CLK_INVERT               (1<<4)
#define SI5351_CLK_INPUT_MASK           (3<<2)
#define SI5351_CLK_INPUT_XTAL           (0<<2)
#define SI5351_CLK_INPUT_CLKIN          (1<<2)
#define SI5351_CLK_INPUT_MULTISYNTH_0_4 (2<<2)
#define SI5351_CLK_INPUT_MULTISYNTH_N   (3<<2)
#define SI5351_CLK_DRIVE_STRENGTH_MASK  (3<<0)
#define SI5351_CLK_DRIVE_STRENGTH_2MA   (0<<0)
#define SI5351_CLK_DRIVE_STRENGTH_4MA   (1<<0)
#define SI5351_CLK_DRIVE_STRENGTH_6MA   (2<<0)
#define SI5351_CLK_DRIVE_STRENGTH_8MA   (3<<0)

#define SI5351_CLK3_0_DISABLE_STATE     24
#define SI5351_CLK7_4_DISABLE_STATE     25
#define SI5351_CLK_DISABLE_STATE_MASK   3
#define SI5351_CLK_DISABLE_STATE_LOW    0
#define SI5351_CLK_DISABLE_STATE_HIGH   1
#define SI5351_CLK_DISABLE_STATE_FLOAT  2
#define SI5351_CLK_DISABLE_STATE_NEVER  3

#define SI5351_PARAMETERS_LENGTH        8
#define SI5351_PLLA_PARAMETERS          26
#define SI5351_PLLB_PARAMETERS          34
#define SI5351_CLK0_PARAMETERS          42
#define SI5351_CLK1_PARAMETERS          50
#define SI5351_CLK2_PARAMETERS          58
#define SI5351_CLK3_PARAMETERS          66
#define SI5351_CLK4_PARAMETERS          74
#define SI5351_CLK5_PARAMETERS          82
#define SI5351_CLK6_PARAMETERS          90
#define SI5351_CLK7_PARAMETERS          91
#define SI5351_CLK6_7_OUTPUT_DIVIDER    92
#define SI5351_OUTPUT_CLK_DIV_MASK      (7 << 4)
#define SI5351_OUTPUT_CLK6_DIV_MASK     (7 << 0)
#define SI5351_OUTPUT_CLK_DIV_SHIFT     4
#define SI5351_OUTPUT_CLK_DIV6_SHIFT    0
#define SI5351_OUTPUT_CLK_DIV_1         0
#define SI5351_OUTPUT_CLK_DIV_2         1
#define SI5351_OUTPUT_CLK_DIV_4         2
#define SI5351_OUTPUT_CLK_DIV_8         3
#define SI5351_OUTPUT_CLK_DIV_16        4
#define SI5351_OUTPUT_CLK_DIV_32        5
#define SI5351_OUTPUT_CLK_DIV_64        6
#define SI5351_OUTPUT_CLK_DIV_128       7
#define SI5351_OUTPUT_CLK_DIVBY4       (3<<2)

#define SI5351_SSC_PARAM0               149
#define SI5351_SSC_PARAM1               150
#define SI5351_SSC_PARAM2               151
#define SI5351_SSC_PARAM3               152
#define SI5351_SSC_PARAM4               153
#define SI5351_SSC_PARAM5               154
#define SI5351_SSC_PARAM6               155
#define SI5351_SSC_PARAM7               156
#define SI5351_SSC_PARAM8               157
#define SI5351_SSC_PARAM9               158
#define SI5351_SSC_PARAM10              159
#define SI5351_SSC_PARAM11              160
#define SI5351_SSC_PARAM12              161

#define SI5351_VXCO_PARAMETERS_LOW      162
#define SI5351_VXCO_PARAMETERS_MID      163
#define SI5351_VXCO_PARAMETERS_HIGH     164

#define SI5351_CLK0_PHASE_OFFSET        165
#define SI5351_CLK1_PHASE_OFFSET        166
#define SI5351_CLK2_PHASE_OFFSET        167
#define SI5351_CLK3_PHASE_OFFSET        168
#define SI5351_CLK4_PHASE_OFFSET        169
#define SI5351_CLK5_PHASE_OFFSET        170

#define SI5351_PLL_RESET                177
#define SI5351_PLL_RESET_B              (1<<7)
#define SI5351_PLL_RESET_A              (1<<5)
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

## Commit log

2021-04-14 Initial KiCad Schematic and PCB files
    [SDRBackup.kicad_pcb, SDRBackup2.kicad_pcb, SDRReciever.kicad_pcb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]
2021-04-14 Removed unnecessary files and components
    [SDRBackup.kicad_pcb, SDRBackup2.kicad_pcb, SDRReciever.sch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]
2021-04-17 Updated values for bandpass filter in KiCad schematic Now a 3-rd order, series first, butterworth filter passing 6-16Mhz Also added some additional comments to KiCad schematic
    [SDRReciever.sch]
2021-04-19 Updated schematic, added voltage converter and comments
    [SDRReciever.sch]
2021-04-27 Updated KiCad Schematic 1. Exchanged instrumentation amplifiers and following op amp low pass filters for a single set of low noise op amps with multiple feedback and two poles of attenuation. 2. Rem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
    [SDRReciever02.sch]
2021-04-27 Removed diodes, added test point
    [SDRReciever02.sch]
2021-04-27 Removed old KiCad version files, kept the latest and removed *02 appending
    [SDRReciever.sch, SDRReciever02.sch]
2021-04-29 Revision 0.3 of schematic Added bypass cap Added DC blocking caps Removed redudant resitors Added custom footprints Updated BNC connector footprint Updated audo jack footprint, schematic symbol, conn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
    [35RAPC4BHN2.step, SDRReciever.kicad_pcb, SDRReciever.sch]
2021-04-29 Added PDFs of Schematic
2021-04-29 Exchanged transistor for surface mount transistor Updated resistor values to standard values
    [SDRReciever.sch]
2021-04-30 Initial PCB part layout complete Trace not routed yet
    [SDRReciever.sch]
2021-04-30 Revised PCB part placement
    [SDRReciever.kicad_pcb]
2021-04-30 Revised placement of PCB parts
    [SDRReciever.kicad_pcb, SDRReciever.sch]
2021-04-30 Initial PCB tracing complete
    [SDRReciever.kicad_pcb]
2021-04-30 Added more vias to improve ground plane on PCB
    [SDRReciever.kicad_pcb]
2021-05-01 Revision 1 complete First complete PCB design.
    [SDRReciever.kicad_pcb, SDRReciever.sch]
2021-05-01 Updated simulation test (got rid of the jumper cable from the RF source to ground)
2021-05-01 PCB revision 1 complete. Added 3D model and updated silk screen.
    [SDRReciever.kicad_pcb]
2021-05-05 Added Gerbers, Drill Files, and Interactive BOM (Bill of Materials)
    [SDRReciever-B_Cu.gbr, SDRReciever-B_Mask.gbr, SDRReciever-B_Paste.gbr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]
2021-05-05 Updated schematic pdfs to latest version (revision 1)
2021-06-02 Added Quisk Software files, updated si5351a oscillator test file. Need to look into clock 1 and clock 2 working with quisk.
    [openradio_quisk_code.ino]
2021-06-11 More updates to readme. Fixed bug with Quisk Code.
    [openradio_quisk.ino, openradio_quisk_old.ino]

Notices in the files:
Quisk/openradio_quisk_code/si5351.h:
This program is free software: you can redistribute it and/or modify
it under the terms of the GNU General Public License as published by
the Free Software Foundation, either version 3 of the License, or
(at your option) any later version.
